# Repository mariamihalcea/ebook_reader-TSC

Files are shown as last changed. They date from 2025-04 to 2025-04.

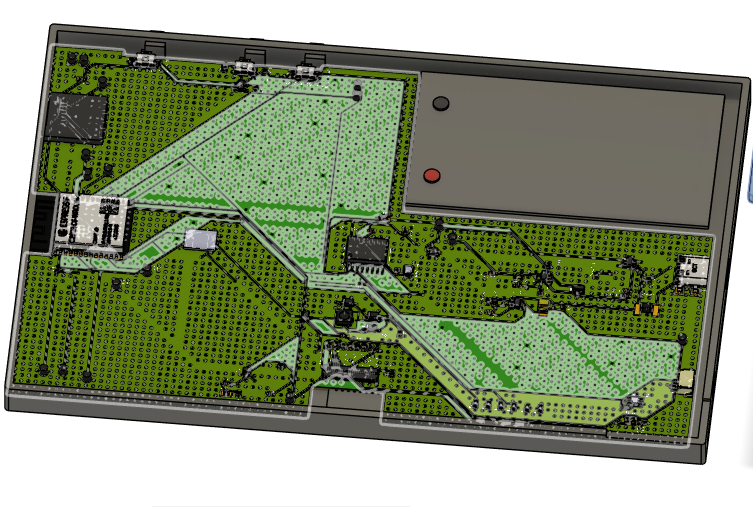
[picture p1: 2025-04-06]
Images/OpenBook_without_lid.png

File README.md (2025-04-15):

# OpenBook E-Reader 

## 1. Diagrama bloc


**Descriere:**

- Microcontrollerul **ESP32-C6** este unitatea centrala care gestioneaza comunicarea cu toate modulele periferice.
- Display-ul e-paper este controlat de un circuit dedicat de comanda.
- Senzorul ambiental **BME688** masoara calitatea aerului si temperatura.
- Memoria externa NOR Flash (64MB) si cardul SD permit stocarea fisierelor (eBook-uri, configurari etc).
- RTC-ul **DS3231SN** asigura ora exacta in mod autonom, chiar si in lipsa alimentarii.
- Incarcarea bateriei Li-Po se face prin USB-C, cu protectie ESD si monitorizare a nivelului de incarcare (MAX17048).
- Butoanele fizice permit resetul sistemului si selectii de tip boot.

---

## 2. Bill Of Materials (BOM)
| Componenta | Link | Datasheet |
|---|---|---|
| BUTTON | [Model](https://industry.panasonic.com/global/en/products/control/switch/light-touch/number/evqpuj02k) | [Datasheet](https://www.lcsc.com/datasheet/lcsc_datasheet_2201121800_PANASONIC-EVQPUJ02K_C2936858.pdf) |
| CAPACITOR | [Model](https://componentsearchengine.com/part-view/R0402%201%25%20100%20K%20(RC0402FR-07100KL)/YAGEO) | [Datasheet](//efaidnbmnnnibpcajpcglclefindmkaj/https://www.resistor.com/assets/pdf/0402tstd.pdf) |
| CPH3225A | [Model](https://www.snapeda.com/parts/CPH3225A/Seiko+Instruments/view-part/?ref=eda) | [Datasheet](https://octopart.com/datasheet/cph3225a-seiko-25340571) |
| EVQPUJ02K | [Model](https://industry.panasonic.com/global/en/products/control/switch/light-touch/number/evqpuj02k) | [Datasheet](https://www.lcsc.com/datasheet/lcsc_datasheet_2201121800_PANASONIC-EVQPUJ02K_C2936858.pdf) |
| KP-1608SURCK | [Model](https://www.snapeda.com/parts/KP-1608SURCK/Kingbright/view-part/?ref=search&t=LED%200603) | [Datasheet](//efaidnbmnnnibpcajpcglclefindmkaj/https://media.elv.com/file/107153_led_surck1608_data.pdf) |
| USBLC6-2SC6Y | [Model](https://www.snapeda.com/parts/USBLC6-2SC6Y/STMicroelectronics/view-part/?ref=eda) | [Datasheet](https://www.digikey.com/en/htmldatasheets/production/1375342/0/0/1/usblc6-2sc6y) |
| SD0805S020S1R0 | [Model](https://ro.mouser.com/ProductDetail/KYOCERA-AVX/SD0805S020S1R0?qs=jCA%252BPfw4LHbpkAoSnwrdjw%3D%3D) | [Datasheet](https://www.alldatasheet.com/view.jsp?Searchword=SD0805S&sField=2) |
| PGB1010603MR | [Model](https://www.snapeda.com/parts/PGB1010603MR/Littelfuse/view-part/?ref=eda) | [Datasheet](https://www.alldatasheet.com/view.jsp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) |
| BD5229G-TR  | [Model](https://componentsearchengine.com/part-view/BD5229G-TR/ROHM%20Semiconductor) | [Datasheet](https://www.lcsc.com/datasheet/lcsc_datasheet_2201131330_ROHM-Semicon-BD5229G-TR_C962636.pdf) |
| XC6220A331MR-G | [Model](https://componentsearchengine.com/part-view/XC6220A331MR-G/Torex) | [Datasheet](https://www.alldatasheet.com/view.jsp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) |
| XC6220A331MR-G | [Model](https://componentsearchengine.com/part-view/XC6220A331MR-G/Torex) | [Datasheet](https://www.alldatasheet.com/view.jsp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) |
| USB4110-GF-A  | [Model](https://componentsearchengine.com/part-view/USB4110-GF-A/GCT%20(GLOBAL%20CONNECTOR%20TECHNOLOGY)) | [Datasheet](//efaidnbmnnnibpcajpcglclefindmkaj/https://gct.co/files/drawings/usb4110.pdf) |
| Adafruit | [Model](https://eu.mouser.com/ProductDetail/Adafruit/4208?qs=PzGy0jfpSMtbScLbr0L5dw%3D%3D) | [Datasheet](https://www.arrow.com/en/manufacturers/adafruit-industries/datasheets) |
| Bobina | [Model](https://store.comet.srl.ro/Catalogue/Product/43497/) | [Datasheet](https://www.scribd.com/document/814581278/Datasheet-Bobina) |
| PFMF | [Model](https://www.mouser.co.uk/ProductDetail/EPCOS-TDK/B72520T0350K062?qs=dEfas%2FXlABIszF52uu7vrg%3D%3D) | [Datasheet](https://ro.mouser.com/c/ds/circuit-protection/thermistors/resettable-fuses-pptc/?m=Schurter&series=PFMF) |
| DMG2305UX-7 | [Model](https://componentsearchengine.com/part-view/DMG2305UX-7/Diodes%20Incorporated) | [Datasheet](//efaidnbmnnnibpcajpcglclefindmkaj/https://www.mouser.com/datasheet/2/115/DMG2305UX-266242.pdf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) |
| Si1308EDL-T1-GE3 | [Model](https://componentsearchengine.com/part-view/SI1308EDL-T1-GE3/Vishay) | [Datasheet](https://www.alldatasheet.com/view.jsp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) |
| R0402 | [Model](https://componentsearchengine.com/part-view/R0402%201%25%20100%20K%20(RC0402FR-07100KL)/YAGEO) | [Datasheet](//efaidnbmnnnibpcajpcglclefindmkaj/https://www.resistor.com/assets/pdf/0402tstd.pdf) |
| BME680 | [Model](https://www.snapeda.com/parts/BME680/Bosch/view-part/?welcome=home) | [Datasheet](//efaidnbmnnnibpcajpcglclefindmkaj/https://www.bosch-sensortec.com/media/boschsensortec/downloads/datasheets/bst-bme680-ds001.pdf) |
| SMD Solder | [Model](https://grabcad.com/library/solder-jumpers-1) | [Datasheet]() |
| W25Q512JVEIQ | [Model](https://www.snapeda.com/parts/ESP32-C6-WROOM-1-N8/Espressif+Systems/view-part/?ref=eda) | [Datasheet](//efaidnbmnnnibpcajpcglclefindmkaj/https://www.mouser.com/datasheet/2/949/W25Q512JV_SPI_RevB_06252019_KMS-2487502.pdf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) |
| ESP32-C6-WROOM-1-N8 | [Model](https://www.snapeda.com/parts/ESP32-C6-WROOM-1-N8/Espressif+Systems/view-part/?ref=eda) | [Datasheet](//efaidnbmnnnibpcajpcglclefindmkaj/https://www.mouser.com/catalog/specsheets/Espressif_ESP32_C6_WROOM_1%20_Datasheet_V0.1_PRELIMINARY_en.pdf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) |
| DS3231SN# | [Model](https://www.snapeda.com/parts/DS3231SN%23/Analog+Devices/view-part/?ref=eda) | [Datasheet](https://www.alldatasheet.com/view.jsp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) |
| MAX17048G+T10 | [Model](https://www.snapeda.com/parts/MAX17048G+T10/Analog+Devices/view-part/?ref=eda) | [Datasheet](https://www.alldatasheet.com/view.jsp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) |
| MCP73831T-5ACI/OT | [Model](https://www.mouser.co.uk/ProductDetail/Microchip-Technology/MCP73831T-5ACI-OT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) | [Datasheet](//efaidnbmnnnibpcajpcglclefindmkaj/https://ww1.microchip.com/downloads/en/DeviceDoc/MCP73831-Family-Data-Sheet-DS20001984H.pdf) |

## 3. Descriere hardware detaliata

###  Microcontroller – ESP32-C6
- Controleaza toate componentele externe prin GPIO, I2C, SPI.

### E-paper Display + Driver
- Controlat prin SPI, cu tensiune separata de alimentare si control.

###  RTC – DS3231SN
- Ceas in timp real cu precizie mare si backup pe baterie.
- Comunicatie I2C cu ESP32-C6.
- Folosit pentru afisarea orei si sincronizare evenimente programate.

### Card SD
- Legat la ESP32 prin SPI.
- Utilizat pentru incarcare/citire fisiere eBook, configurari etc.

###  Senzor mediu – BME688
- Comunica prin I2C.
- Masoara temperatura, presiune, umiditate si compusi volatili.

###  Conector USB-C
- Folosit pentru incarcare si posibila conectare seriala cu PC pentru debug.

##  4. Conexiuni ESP32-C6

| Componenta | Pin ESP32-C6 | Interfata | Motiv utilizare |
|---|---|---|---|
| E-paper Display | IO06, IO07, IO08  | SPI | Transfer rapid de date catre display |
| Flash NOR | IO10, IO11, IO12  | SPI | Stocare externa rapida |
| Senzor BME688 | IO18 (SDA), IO19 (SCL) | I2C | Comunicare cu senzori |
| RTC DS3231SN | IO18, IO19 | I2C | Reutilizeaza magistrala I2C |
| MAX17048 (Baterie) | IO18, IO19 | I2C | Monitor baterie, I2C comun |
| SD Card | IO01, IO02, IO03  | SPI | Citire fisiere eBook |
| Buton reset/boot | IO00, EN | GPIO | Control boot si reset manual |

---

## 5. Pasi de implementare

### 1. Analiza documentatiei initiale
Am analizat schematicul si layout-ul placii furnizate de profesor. Pe baza acestora, am recreat designul electronic in Fusion Electronics, atat schema electrica, cat si placa PCB.

### 2. Plasarea componentelor pe PCB
Am asezat componentele pe placa, urmarind o pozitionare si orientare optime, pentru a permite o rutare eficienta si functionala.

### 3. Rutarea traseelor
Traseele de alimentare au fost rutate manual pentru a asigura robustete si dimensiuni corecte. Conexiunile ramase au fost rutate automat, folosind functia de autorouting pe ambele straturi (top si bottom). Am adaugat polygon pour pentru a crea plane de masa pe ambele straturi.

### 4. Optimizarea layout-ului
Am folosit vias pentru a conecta planele de masa intre straturi si pentru a completa zonele neconectate. Am aplicat via stitching pentru a imbunatati integritatea electrica a designului.

### 5. Generarea modelului 3D al placii
Pe baza designului 2D, am generat modelul 3D al placii. Am cautat si importat manual fiecare componenta 3D, pozitionandu-le conform plasamentului din PCB-ul 2D. Pentru componenta *test pad*, neavand un model disponibil online, am creat manual unul pentru a reprezenta corect placa in ansamblu.

### 6. Integrarea in ansamblul final – OpenBook Enclosure
Am importat modelul 3D al placii in fisierul principal al carcasei (OpenBook Enclosure). Acolo am plasat toate componentele in carcasa finala pentru a asigura o potrivire corecta si functionala. Display-ul si bateria au fost desenate manual pentru a fi integrate in ansamblu si pentru a oferi o reprezentare cat mai realista a produsului final.
##  6. Alte detalii relevante

La realizarea PCB-ului am intampinat si doua erori de Copper Width, desi aveam  dimensiunile corespunzatoare, asa ca le-am aprobat.

<br>
si doua erori din cauza dimensiunii gaurilor din mufa USB, pe care de asemenea le am aprobat


---

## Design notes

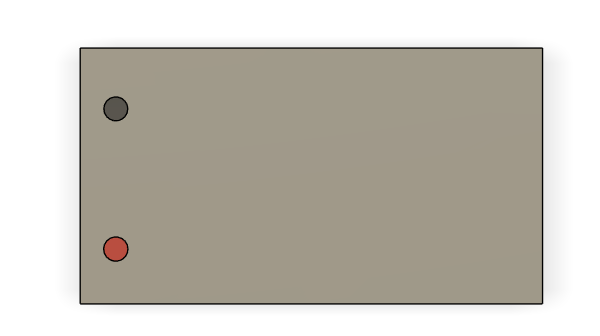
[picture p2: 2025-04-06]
Images/battery.png

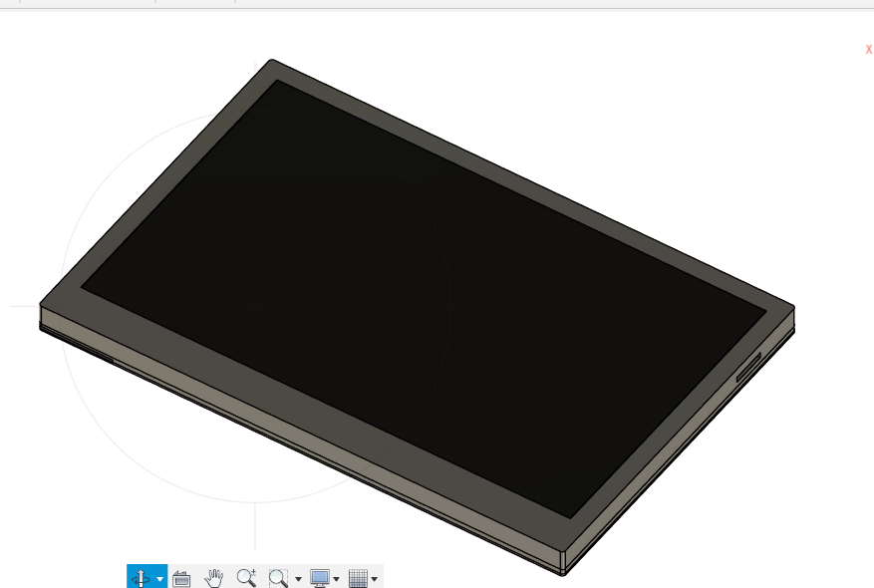
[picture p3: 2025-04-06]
Images/board_bottom.png

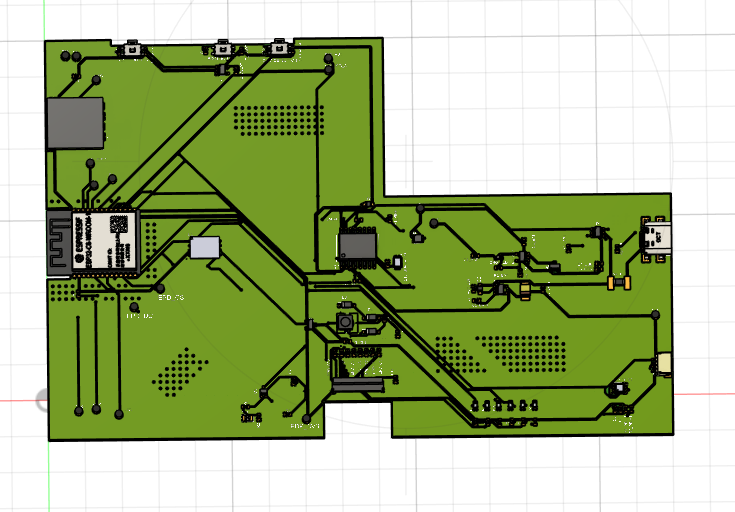
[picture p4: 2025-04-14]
Images/pcb-top.png

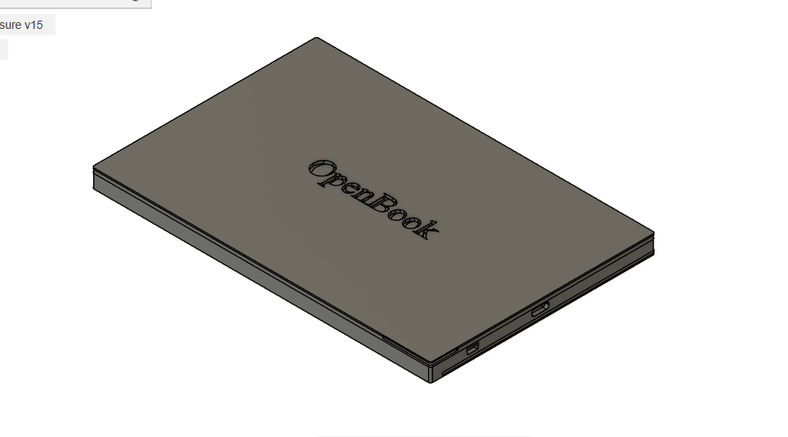
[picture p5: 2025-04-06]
Images/OpenBook.png

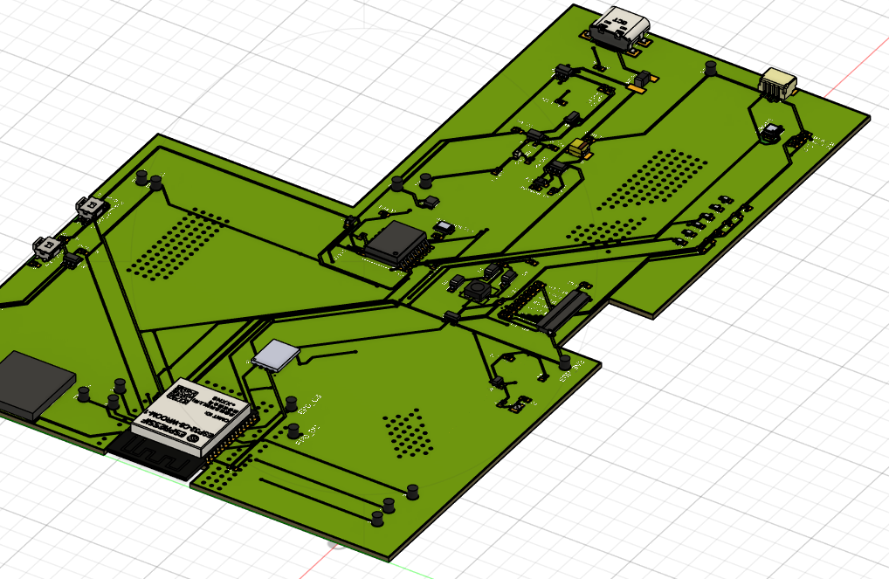
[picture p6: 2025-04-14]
Images/pcb.png

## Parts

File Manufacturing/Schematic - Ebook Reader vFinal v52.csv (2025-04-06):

Qty | Value | Device | Package | Parts | Description | ARROW_PART_NUMBER | ARROW_PRICE-STOCK | AVAILABILITY | CENTROID_NOT_SPECIFIED | CHECK_PRICES | COPYRIGHT | DATASHEET | DESCRIPTION | DIGIKEY_DESCRIPTION | DIGIKEY_PART_NUMBER | HEIGHT | LEAD_FREE | MANUFACTURER_NAME | MANUFACTURER_PART_NUMBER | MF | MFR_NAME | MOUSER_PART_NUMBER | MOUSER_PRICE-STOCK | MOUSER_TESTING_PART_NUMBER | MOUSER_TESTING_PRICE-STOCK | MP | MPN | PACKAGE | POPULARITY | PREFIX | PRICE | PROD_ID | PURCHASE-URL | ROHS | SNAPEDA_LINK | SPICEMODEL | SPICEPREFIX | TEMPERATURE_RANGE_HIGH | TEMPERATURE_RANGE_LOW | TP_SIGNAL_NAME | VALUE
1 |  | ADAFRUIT_LEDCHIP-LED0603 | ADAFRUIT_CHIP-LED0603 | CHG_LED | LED
1 |  | SJ | SJ | SJ1 | SMD solder JUMPER |  |  |  |  |  |  |  |  |  |  |  |  |  |  |  |  |  |  |  |  |  |  |  | 3
1 | 0.1uF_50V | EAGLE-LTSPICE_CC0402 | EAGLE-LTSPICE_C0402 | EPD_C5 | CAPACITOR, European symbol |  |  |  |  |  |  |  |  |  |  |  |  |  |  |  |  |  |  |  |  |  |  |  |  |  |  |  |  |  |  | NONE | C
1 | 0.47 | ESP32_WROVER_EAGLE-LTSPICE_RR0402 | ESP32_WROVER_EAGLE-LTSPICE_R0402 | R3 | RESISTOR, European symbol |  |  |  |  |  |  |  |  |  |  |  |  |  |  |  |  |  |  |  |  |  |  |  |  |  |  |  |  |  |  | NONE | R
1 | 100K | ESP32_WROVER_EAGLE-LTSPICE_RR0402 | ESP32_WROVER_EAGLE-LTSPICE_R0402 | R1_PWRUSB | RESISTOR, European symbol |  |  |  |  |  |  |  |  |  |  |  |  |  |  |  |  |  |  |  |  |  |  |  |  |  |  |  |  |  |  | NONE | R
8 | 100nF | EAGLE-LTSPICE_CC0402 | EAGLE-LTSPICE_C0402 | C1, C2, C4_USB, C6, C8, C9, C10, C_DELAY | CAPACITOR, European symbol |  |  |  |  |  |  |  |  |  |  |  |  |  |  |  |  |  |  |  |  |  |  |  |  |  |  |  |  |  |  | NONE | C
1 | 100uF TANT | RCL_CPOL-EUCT3528 | RCL_CT3528 | C3 | POLARIZED CAPACITOR, European symbol |  |  |  |  |  |  |  |  |  |  |  |  |  |  |  |  |  |  |  |  |  |  |  | 0 |  |  |  |  |  |  |  | C
13 | 10K | ESP32_WROVER_EAGLE-LTSPICE_RR0402 | ESP32_WROVER_EAGLE-LTSPICE_R0402 | R1, R1_PINH, R1_PINH1, R4, R5, R6, R7, R8, R9, R10, R_BOOT, R_CHANGE, R_RESET | RESISTOR, European symbol |  |  |  |  |  |  |  |  |  |  |  |  |  |  |  |  |  |  |  |  |  |  |  |  |  |  |  |  |  |  | NONE | R
3 | 10k | ESP32_WROVER_EAGLE-LTSPICE_RR0402 | ESP32_WROVER_EAGLE-LTSPICE_R0402 | R2_PINH, R2_PINH1, R_CL1 | RESISTOR, European symbol |  |  |  |  |  |  |  |  |  |  |  |  |  |  |  |  |  |  |  |  |  |  |  |  |  |  |  |  |  |  | NONE | R
1 | 10uF | EAGLE-LTSPICE_CC0402 | EAGLE-LTSPICE_C0402 | C7 | CAPACITOR, European symbol |  |  |  |  |  |  |  |  |  |  |  |  |  |  |  |  |  |  |  |  |  |  |  |  |  |  |  |  |  |  | NONE | C
1 | 112A-TAAR-R03_ATTEND | 112A-TAAR-R03_ATTEND | 112ATAARR03ATTEND | J4 | Micro SD Card Socket, Push-Push Type, Top Mount, SMT, H=1.83mm, 10u |  |  |  |  |  |  |  | Micro SD Card Socket | Push-Push Type | Top Mount | SMT | H=1.83mm | 10u |  |  | 1.9mm |  | ATTEND | 112A-TAAR-R03 ATTEND
1 | 15 | ESP32_WROVER_EAGLE-LTSPICE_RR0402 | ESP32_WROVER_EAGLE-LTSPICE_R0402 | R_CAPACITOR | RESISTOR, European symbol |  |  |  |  |  |  |  |  |  |  |  |  |  |  |  |  |  |  |  |  |  |  |  |  |  |  |  |  |  |  | NONE | R
1 | 1uF | EAGLE-LTSPICE_CC0402 | EAGLE-LTSPICE_C0402 | C5 | CAPACITOR, European symbol |  |  |  |  |  |  |  |  |  |  |  |  |  |  |  |  |  |  |  |  |  |  |  |  |  |  |  |  |  |  | NONE | C
1 | 1uF/50v | EAGLE-LTSPICE_CC0402 | EAGLE-LTSPICE_C0402 | EPD_C12 | CAPACITOR, European symbol |  |  |  |  |  |  |  |  |  |  |  |  |  |  |  |  |  |  |  |  |  |  |  |  |  |  |  |  |  |  | NONE | C
8 | 1uF_50V | EAGLE-LTSPICE_CC0402 | EAGLE-LTSPICE_C0402 | EPD_C1, EPD_C2, EPD_C6, EPD_C7, EPD_C8, EPD_C9, EPD_C10, EPD_C11 | CAPACITOR, European symbol |  |  |  |  |  |  |  |  |  |  |  |  |  |  |  |  |  |  |  |  |  |  |  |  |  |  |  |  |  |  | NONE | C
1 | 2.2 | ESP32_WROVER_EAGLE-LTSPICE_RR0402 | ESP32_WROVER_EAGLE-LTSPICE_R0402 | R2 | RESISTOR, European symbol |  |  |  |  |  |  |  |  |  |  |  |  |  |  |  |  |  |  |  |  |  |  |  |  |  |  |  |  |  |  | NONE | R
1 | 200 | ESP32_WROVER_EAGLE-LTSPICE_RR0402 | ESP32_WROVER_EAGLE-LTSPICE_R0402 | R1_BAT | RESISTOR, European symbol |  |  |  |  |  |  |  |  |  |  |  |  |  |  |  |  |  |  |  |  |  |  |  |  |  |  |  |  |  |  | NONE | R
2 | 20V/4.2A/52mO/1.4W | ESP32_WROVER_SPARKFUN-DISCRETESEMI_MOSFET_PCH-DMG2305UX-7 | ESP32_WROVER_SPARKFUN-DISCRETESEMI_SOT23-3 | Q1, Q2 | P-channel MOSFETs |  |  |  |  |  |  |  |  |  |  |  |  |  |  |  |  |  |  |  |  |  |  |  |  |  |  | TRAN-14388 |  |  |  |  |  |  |  |  | 20V/4.2A/52mO/1.4W
1 | 2K | ESP32_WROVER_EAGLE-LTSPICE_RR0402 | ESP32_WROVER_EAGLE-LTSPICE_R0402 | R2_BAT | RESISTOR, European symbol |  |  |  |  |  |  |  |  |  |  |  |  |  |  |  |  |  |  |  |  |  |  |  |  |  |  |  |  |  |  | NONE | R
5 | 4.7uF | EAGLE-LTSPICE_CC0402 | EAGLE-LTSPICE_C0402 | C1_BAT, C1_BAT1, C1_BAT2, C2_BAT, C5_USB | CAPACITOR, European symbol |  |  |  |  |  |  |  |  |  |  |  |  |  |  |  |  |  |  |  |  |  |  |  |  |  |  |  |  |  |  | NONE | C
1 | 4.7uF/25V | EAGLE-LTSPICE_CC0402 | EAGLE-LTSPICE_C0402 | C4 | CAPACITOR, European symbol |  |  |  |  |  |  |  |  |  |  |  |  |  |  |  |  |  |  |  |  |  |  |  |  |  |  |  |  |  |  | NONE | C
2 | 5k1 | ESP32_WROVER_EAGLE-LTSPICE_RR0402 | ESP32_WROVER_EAGLE-LTSPICE_R0402 | R2-USB, R2-USB1 | RESISTOR, European symbol |  |  |  |  |  |  |  |  |  |  |  |  |  |  |  |  |  |  |  |  |  |  |  |  |  |  |  |  |  |  | NONE | R
1 | 68uH | 744043680IND_4828-WE-TPC_WRE | IND_4828-WE-TPC_WRE | L1 |  |  |  |  |  |  | Copyright (C) 2024 Ultra Librarian. All rights reserved. |  |  |  |  |  |  |  | 744043680 |  | Wurth Electronics
1 | BD5229G-TR | BD5229G-TR | SOT95P280X125-5N | IC1 | Voltage Detector with Adjustable Delay Time: CMOS processes are utilized to develop high precision, low current consumption CMOS reset ICs that allow arbitrary setting of the delay time. The extensive lineup includes both Nch Open Drain and CMOS output types in a wide range of detection voltages (from 2.3V to 6.0V, in 0.1V steps), enabling selection of the ideal solution based on customer requirements. In addition, the entire series is of course both lead-free and RoHS-compliant. |  |  |  |  |  |  |  | Voltage Detector with Adjustable Delay Time: CMOS processes are utilized to develop high precision | low current consumption CMOS reset ICs that allow arbitrary setting of the delay time. The extensive lineup includes both Nch Open Drain and CMOS output types in a wide range of detection voltages (from 2.3V to 6.0V | in 0.1V steps) | enabling selection of the ideal solution based on customer requirements. In addition | the entire series is of course both lead-free and RoHS-compliant. |  |  | 1.25mm |  | ROHM Semiconductor | BD5229G-TR |  |  | 755-BD5229G-TR | https://www.mouser.co.uk/ProductDetail/ROHM-Semiconductor/BD5229G-TR?qs=4kLU8WoGk0vvnhrrYwdszw%3D%3D
1 | BME688 | ESP32_WROVER_BME680_BME680 | ESP32_WROVER_BME680_PSON80P300X300X100-8N | SENSOR2 | Integrated Environmental Unit |  |  | Unavailable |  |  |  |  | Integrated Environmental Unit |  |  |  |  |  |  | Bosch Sensortec |  |  |  |  |  | BME680 |  | LGA-8 Bosch Tools |  |  | None
3 | BUTTON_CUSYOMV1 | BUTTON_CUSYOMV1 | MYBUTTON | BOOT_BUTTON, CHANGE_BUTTON, RESET_BUTTON
1 | CPH3225A | CPH3225A | CAPCP3225X100N | C10_SUPERCAP | Cap 0.011F 3.3V 1210 Flat Check availability |  |  | Not in stock |  | https://www.snapeda.com/parts/CPH3225A/Seiko+Instruments/view-part/?ref=eda |  |  | 11 mF (EDLC) Supercapacitor 3.3 V 1210 (3225 Metric) - - |  |  |  |  |  |  | Seiko Instruments |  |  |  |  |  | CPH3225A |  | 1210 Seiko |  |  | None |  | https://www.snapeda.com/api/url_track_click_mouser/?unipart_id=562593&manufacturer=Seiko Instruments&part_name=CPH3225A&search_term=None |  | https://www.snapeda.com/parts/CPH3225A/Seiko+Instruments/view-part/?ref=snap
1 | DS3231SN# | DS3231SN# | SOIC127P1032X265-16N | U3 | Real Time Clock Serial 16-Pin SOIC W T/R Check availability |  |  | In Stock |  | https://www.snapeda.com/parts/DS3231SN%23/Analog+Devices/view-part/?ref=eda |  |  | Extremely Accurate I²C-Integrated RTC/TCXO/Crystal |  |  |  |  |  |  | Analog Devices |  |  |  |  |  | DS3231SN# |  | SOIC-16 Maxim |  |  | None |  | https://www.snapeda.com/api/url_track_click_mouser/?unipart_id=99048&manufacturer=Analog Devices&part_name=DS3231SN#&search_term=None |  | https://www.snapeda.com/parts/DS3231SN%23/Analog+Devices/view-part/?ref=snap
1 | ESP32-C6-WROOM-1-N8 | ESP32-C6-WROOM-1-N8 | XCVR_ESP32-C6-WROOM-1-N8 | U2 | Check availability |  |  | In Stock |  | https://www.snapeda.com/parts/ESP32-C6-WROOM-1-N8/Espressif+Systems/view-part/?ref=eda |  |  | Multiprotocol Modules ESP32-C6 module | Wi-Fi 6 in 2.4 GHz band | Bluetooth 5 | Zigbee 3.0 and Thread. ESP34-WROOM Compatible - ENGINEERING SAMPLE |  |  |  |  |  |  | Espressif Systems |  |  |  |  |  | ESP32-C6-WROOM-1-N8 |  | None |  |  | None |  |  |  | https://www.snapeda.com/parts/ESP32-C6-WROOM-1-N8/Espressif+Systems/view-part/?ref=snap
1 | ESP32C6_VARISTORCN1812 | ESP32C6_VARISTORCN1812 | ESP32C6_VARISTOR_CT/CN1812 | PFMF.050.1 | VARISTOR |  |  |  |  |  |  |  |  |  |  |  |  |  |  |  |  |  |  |  |  |  |  |  | 0
2 | ESP32_WROVER_AVX---SD0805S020S1R0_AVX_SD0805S020S1R0_0_0AVX_SD0805S020S1R0_0_0 | ESP32_WROVER_AVX---SD0805S020S1R0_AVX_SD0805S020S1R0_0_0AVX_SD0805S020S1R0_0_0 | ESP32_WROVER_AVX---SD0805S020S1R0_AVX_SD0805S020S1R0_0 | D2, D7 | Schottky Barrier Rectifier Diode |  |  |  | No |  |  | http://datasheets.avx.com/schottky.pdf |  | DIODE SCHOTTKY 20V 1A 0805 | 478-7800-1-ND |  | yes |  |  | AVX |  | 581-SD0805S020S1R0 |  |  |  |  |  | 0805 (2012 metric) |  | D |  |  |  | yes |  |  |  | +125°C | -55°C
1 | ESP32_WROVER_SPARKFUN-IC-POWER_MCP73831 | ESP32_WROVER_SPARKFUN-IC-POWER_MCP73831 | ESP32_WROVER_SPARKFUN-IC-POWER_SOT23-5 | MCP73831 | MCP73831T Li-Ion, Li-Pol Controller |  |  |  |  |  |  |  |  |  |  |  |  |  |  |  |  |  |  |  |  |  |  |  |  |  |  | IC-09995
1 | FH34SRJ-24S-0.5SH_99_ | FH34SRJ-24S-0.5SH_99_ | FH34SRJ24S05SH99 | J1 | (0.50mm) Surface Mount, Right Angle |  |  |  |  |  |  |  | 24 Position FFC | FPC Connector Contacts | (0.50mm) Surface Mount | Right Angle |  |  | 1.1mm |  | Hirose | FH34SRJ-24S-0.5SH(99) |  |  | 798-FH34SRJ24S05SH99 | https://www.mouser.co.uk/ProductDetail/Hirose-Connector/FH34SRJ-24S-0.5SH99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
1 | MAX17048G+T10 | MAX17048G+T10 | SON50P200X200X80-9N | U4 | Check availability |  |  | In Stock |  | https://www.snapeda.com/parts/MAX17048G+T10/Analog+Devices/view-part/?ref=eda |  |  | 3µA 1-Cell/2-Cell Fuel Gauge with ModelGauge |  |  |  |  |  |  | Analog Devices |  |  |  |  |  | MAX17048G+T10 |  | TDFN-8 Maxim |  |  | None |  | https://www.snapeda.com/api/url_track_click_mouser/?unipart_id=329239&manufacturer=Analog Devices&part_name=MAX17048G+T10&search_term=None |  | https://www.snapeda.com/parts/MAX17048G+T10/Analog+Devices/view-part/?ref=snap
3 | MBR0530 | MBR0530 | SOD3716X135N | D3, D4, D5 | ON SEMICONDUCTOR - MBR0530 - DIODE, SCHOTTKY, 0.5A, 30V, SOD-123 |  |  | In Stock |  | https://www.snapeda.com/parts/MBR0530/Onsemi/view-part/?ref=eda |  |  | Diode Schottky 30 V 500mA Surface Mount SOD-123 |  |  |  |  |  |  | ON Semiconductor |  |  |  |  |  | MBR0530 |  | SOD-123-2 ON Semiconductor |  |  | None |  | https://www.snapeda.com/api/url_track_click_mouser/?unipart_id=179458&manufacturer=ON Semiconductor&part_name=MBR0530&search_term=None |  | https://www.snapeda.com/parts/MBR0530/Onsemi/view-part/?ref=snap
6 | PGB1010603MR | PGB1010603MR | DIOC1608X36N | D6, D8, D9, D10, D11, D12 | Check availability |  |  | In Stock |  | https://www.snapeda.com/parts/PGB1010603MR/Littelfuse/view-part/?ref=eda |  |  | 150V (Typ) Clamp - Ipp Tvs Diode Surface Mount 0603 (1608 Metric) |  |  |  |  |  |  | Littelfuse Inc. |  |  |  |  |  | PGB1010603MR |  | 0603 Littelfuse Inc. |  |  | None |  | https://www.snapeda.com/api/url_track_click_mouser/?unipart_id=5659453&manufacturer=Littelfuse Inc.&part_name=PGB1010603MR&search_term=None |  | https://www.snapeda.com/parts/PGB1010603MR/Littelfuse/view-part/?ref=snap
1 | QWIIC_RIGHT_ANGLE | QWIIC_CONNECTORJS-1MM | JST04_1MM_RA | J3 | SparkFun I2C Standard Qwiic Connector |  |  |  |  |  |  |  |  |  |  |  |  |  |  |  |  |  |  |  |  |  |  |  |  |  |  | CONN-13694 |  |  |  |  |  |  |  |  | QWIIC_RIGHT_ANGLE
1 | SAMACSYS_PARTS_USB4110-GF-A | SAMACSYS_PARTS_USB4110-GF-A | SAMACSYS_PARTS_USB4110GFA | J2 | CONN USB 2.0 TYPE-C R/A SMT |  |  |  |  |  |  |  | CONN USB 2.0 TYPE-C R/A SMT |  |  | 3.26mm |  | GCT (GLOBAL CONNECTOR TECHNOLOGY) | USB4110-GF-A |  |  | 640-USB4110-GF-A | https://www.mouser.co.uk/ProductDetail/GCT/USB4110-GF-A?qs=KUoIvG%2F9IlYiZvIXQjyJeA%3D%3D
1 | SI1308EDL-T1-GE3 | SI1308EDL-T1-GE3 | SOT65P210X110-3N | Q3 | MOSFET N-Ch 30V 1.5A TrenchFET SC70 Vishay Si1308EDL-T1-GE3 N-channel MOSFET Transistor, 1.5 A, 30 V, 3-Pin SC-70 |  |  | In Stock |  | https://www.snapeda.com/parts/SI1308EDL-T1-GE3/Vishay+Siliconix/view-part/?ref=eda |  |  | Si1308EDL-T1-GE3 N-channel MOSFET Transistor | 1.5 A | 30 V | 3-Pin SC-70 | Siliconix / Vishay SI1308EDL-T1-GE3 |  |  |  |  |  |  | Vishay Siliconix |  |  |  |  |  | SI1308EDL-T1-GE3 |  | SOT-323 Vishay Semiconductor |  |  | None |  | https://www.snapeda.com/api/url_track_click_mouser/?unipart_id=274603&manufacturer=Vishay Siliconix&part_name=SI1308EDL-T1-GE3&search_term=None |  | https://www.snapeda.com/parts/SI1308EDL-T1-GE3/Vishay+Siliconix/view-part/?ref=snap
17 | TPTP20R | TPTP20R | TP20R | TP1, TP2, TP3, TP4, TP5, TP6, TP7, TP8, TP9, TP10, TP11, TP12, TP13, TP14, TP15, TP16, TP17 | Test pad |  |  |  |  |  |  |  |  |  |  |  |  |  |  |  |  |  |  |  |  |  |  |  | 2
1 | USBLC6-2SC6Y | USBLC6-2SC6Y | SOT95P280X145-6N | D1 | Low Cap. ESD Protection Auto SOT-23-6 STMicroelectronics USBLC6-2SC6Y, Dual Uni-Directional TVS Diode Array, 6-Pin SOT-23 |  |  | In Stock |  | https://www.snapeda.com/parts/USBLC6-2SC6Y/STMicroelectronics/view-part/?ref=eda |  |  | 17V Clamp 5A (8/20µs) Ipp Tvs Diode Surface Mount SOT-23-6 |  |  |  |  |  |  | STMicroelectronics |  |  |  |  |  | USBLC6-2SC6Y |  | SOT-23-6 STMicroelectronics |  |  | None |  |  |  | https://www.snapeda.com/parts/USBLC6-2SC6Y/STMicroelectronics/view-part/?ref=snap
1 | W25Q512JVEIQ | W25Q512JVEIQ | SON127P600X800X80-9N | U1 | Check availability |  |  | In Stock |  | https://www.snapeda.com/parts/W25Q512JVEIQ/Winbond+Electronics/view-part/?ref=eda |  |  | FLASH - NOR Memory IC 512Mb (64M x 8) SPI - Quad I/O 133 MHz 8-WSON (8x6) |  |  |  |  |  |  | Winbond Electronics |  |  |  |  |  | W25Q512JVEIQ |  | Package |  |  | None |  |  |  | https://www.snapeda.com/parts/W25Q512JVEIQ/Winbond+Electronics/view-part/?ref=snap
1 | XC6220A331MR-G | XC6220A331MR-G | SOT95P280X120-5N | IC4 | LDO Voltage Regulators |  |  |  |  |  |  |  | LDO Voltage Regulators |  |  | 1.2mm |  | Torex | XC6220A331MR-G |  |  | 865-XC6220A331MR-G | https://www.mouser.co.uk/ProductDetail/Torex-Semiconductor/XC6220A331MR-G?qs=AsjdqWjXhJ8ZSWznL1J0gg%3D%3D

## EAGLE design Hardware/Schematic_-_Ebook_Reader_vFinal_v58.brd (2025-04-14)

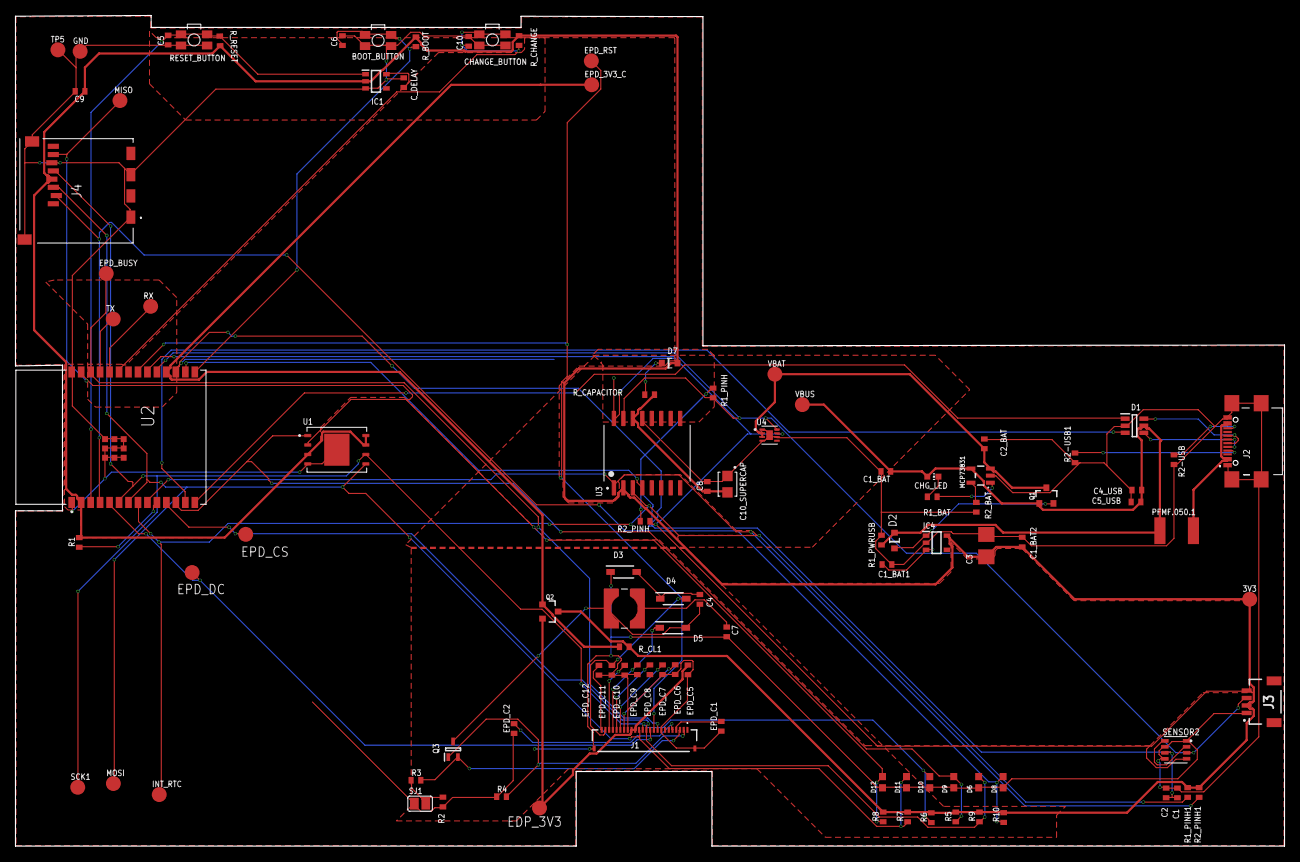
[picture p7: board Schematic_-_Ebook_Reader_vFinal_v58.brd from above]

Board: 2 copper layers, 170.2 x 111.4 mm, 103 parts (0 on the bottom side), 57 nets.

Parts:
3V3: TPTP20R; TP20R
BOOT_BUTTON: BUTTON_CUSYOMV1; MYBUTTON
C1, C2, C4_USB, C6, C8, C9, C10: 100nF; EAGLE-LTSPICE_C0402
C1_BAT, C1_BAT1, C1_BAT2, C2_BAT, C5_USB: 4.7uF; EAGLE-LTSPICE_C0402
C3: 100uF TANT; RCL_CT3528
C4: 4.7uF/25V; EAGLE-LTSPICE_C0402
C5: 1uF; EAGLE-LTSPICE_C0402
C7: 10uF; EAGLE-LTSPICE_C0402
C10_SUPERCAP: CPH3225A; CAPCP3225X100N
CHANGE_BUTTON: BUTTON_CUSYOMV1; MYBUTTON
CHG_LED: ADAFRUIT_CHIP-LED0603
C_DELAY: 100nF; EAGLE-LTSPICE_C0402
D1: USBLC6-2SC6Y; SOT95P280X145-6N
D2, D7: ESP32_WROVER_AVX---SD0805S020S1R0_AVX_SD0805S020S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; ESP32_WROVER_AVX---SD0805S020S1R0_AVX_SD0805S020S1R0_0
D3, D4, D5: MBR0530; SOD3716X135N
D6, D8, D9, D10, D11, D12: PGB1010603MR; DIOC1608X36N
EDP_3V3: TPTP20R; TP20R
EPD_3V3_C: TPTP20R; TP20R
EPD_BUSY: TPTP20R; TP20R
EPD_C1, EPD_C2, EPD_C6, EPD_C7, EPD_C8, EPD_C9, EPD_C10, EPD_C11: 1uF_50V; EAGLE-LTSPICE_C0402
EPD_C5: 0.1uF_50V; EAGLE-LTSPICE_C0402
EPD_C12: 1uF/50v; EAGLE-LTSPICE_C0402
EPD_CS: TPTP20R; TP20R
EPD_DC: TPTP20R; TP20R
EPD_RST: TPTP20R; TP20R
GND: TPTP20R; TP20R
IC1: BD5229G-TR; SOT95P280X125-5N
IC4: XC6220A331MR-G; SOT95P280X120-5N
INT_RTC: TPTP20R; TP20R
J1: FH34SRJ-24S-0.5SH_99_; FH34SRJ24S05SH99
J2: SAMACSYS_PARTS_USB4110-GF-A; SAMACSYS_PARTS_USB4110GFA
J3: QWIIC_RIGHT_ANGLE; JST04_1MM_RA
J4: 112A-TAAR-R03_ATTEND; 112ATAARR03ATTEND
L1: 68uH; IND_4828-WE-TPC_WRE
MCP73831: ESP32_WROVER_SPARKFUN-IC-POWER_MCP73831; ESP32_WROVER_SPARKFUN-IC-POWER_SOT23-5
MISO: TPTP20R; TP20R
MOSI: TPTP20R; TP20R
PFMF.050.1: ESP32C6_VARISTORCN1812; ESP32C6_VARISTOR_CT/CN1812
Q1, Q2: 20V/4.2A/52mΩ/1.4W; ESP32_WROVER_SPARKFUN-DISCRETESEMI_SOT23-3
Q3: SI1308EDL-T1-GE3; SOT65P210X110-3N
R1, R1_PINH, R1_PINH1, R4, R5, R6, R7, R8, R9, R10: 10K; ESP32_WROVER_EAGLE-LTSPICE_R0402
R1_BAT: 200; ESP32_WROVER_EAGLE-LTSPICE_R0402
R1_PWRUSB: 100K; ESP32_WROVER_EAGLE-LTSPICE_R0402
R2: 2.2; ESP32_WROVER_EAGLE-LTSPICE_R0402
R2-USB, R2-USB1: 5k1; ESP32_WROVER_EAGLE-LTSPICE_R0402
R2_BAT: 2K; ESP32_WROVER_EAGLE-LTSPICE_R0402
R2_PINH, R2_PINH1: 10k; ESP32_WROVER_EAGLE-LTSPICE_R0402
R3: 0.47; ESP32_WROVER_EAGLE-LTSPICE_R0402
RESET_BUTTON: BUTTON_CUSYOMV1; MYBUTTON
RX: TPTP20R; TP20R
R_BOOT: 10K; ESP32_WROVER_EAGLE-LTSPICE_R0402
R_CAPACITOR: 15; ESP32_WROVER_EAGLE-LTSPICE_R0402
R_CHANGE: 10K; ESP32_WROVER_EAGLE-LTSPICE_R0402
R_CL1: 10k; ESP32_WROVER_EAGLE-LTSPICE_R0402
R_RESET: 10K; ESP32_WROVER_EAGLE-LTSPICE_R0402
SCK1: TPTP20R; TP20R
SENSOR2: BME688; ESP32_WROVER_BME680_PSON80P300X300X100-8N
SJ1: SJ
TP5: TPTP20R; TP20R
TX: TPTP20R; TP20R
U1: W25Q512JVEIQ; SON127P600X800X80-9N
U2: ESP32-C6-WROOM-1-N8; XCVR_ESP32-C6-WROOM-1-N8
U3: DS3231SN#; SOIC127P1032X265-16N
U4: MAX17048G+T10; SON50P200X200X80-9N
VBAT: TPTP20R; TP20R
VBUS: TPTP20R; TP20R

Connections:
3V3: 3V3.TP, C1_BAT2.1, C3.+, C9.1, D7.2, IC1.2, IC4.5, J3.2, J4.P4, Q2.3, R1.2, R1_PINH1.2, R2_PINH1.2, R5.2, R6.2, R7.2, R8.2, R9.2, R10.2, R_BOOT.2, R_CHANGE.2, R_CL1.2, R_RESET.2, U1.3, U1.7, U1.8, U2.2, U3.2
32KHZ: R2_PINH1.1, U2.9, U3.1
DN: D1.4, J2.A7, J2.B7
DP: D1.6, J2.A6, J2.B6
EPD_3V3: EDP_3V3.TP, EPD_C5.2, J1.15, J1.16, Q2.2
EPD_3V3_C: EPD_3V3_C.TP, Q2.1, R_CL1.1, U2.18
EPD_BUSY: EPD_BUSY.TP, J1.9, U2.26
EPD_CS: D6.2, EPD_CS.TP, J1.12, R9.1, U2.11
EPD_DC: EPD_DC.TP, J1.11, U2.5
EPD_RST: EPD_RST.TP, J1.10, U2.21
FLASH_CS: D9.2, R5.1, U1.1, U2.12
GDR: J1.2, Q3.1, R4.2
GND: BOOT_BUTTON.1, BOOT_BUTTON.2, C1.2, C1_BAT.2, C1_BAT1.2, C1_BAT2.2, C2.2, C2_BAT.2, C3.-, C4_USB.2, C5.2, C5_USB.2, C6.2, C7.2, C8.2, C9.2, C10.2, C10_SUPERCAP.1, CHANGE_BUTTON.1, CHANGE_BUTTON.2, C_DELAY.2, D1.2, D3.1, D6.1, D8.1, D9.1, D10.1, D11.1, D12.1, EPD_C1.1, EPD_C2.1, EPD_C5.1, EPD_C6.1, EPD_C7.1, EPD_C9.1, EPD_C10.1, EPD_C11.1, EPD_C12.1, GND.TP, IC1.3, IC4.2, J1.8, J1.17, J1.MP1, J1.MP2, J2.A1, J2.A12, J2.B1, J2.B12, J2.MP1, J2.MP2, J2.MP3, J2.MP4, J3.1, J4.G1, J4.G2, J4.G3, J4.G4, J4.P6, MCP73831.2, R1_PWRUSB.2, R2.1, R2-USB.2, R2-USB1.1, R2_BAT.1, R4.1, RESET_BUTTON.1, RESET_BUTTON.2, SENSOR2.1, SENSOR2.5, SENSOR2.7, SJ1.1, TP5.TP, U1.4, U1.9, U2.1, U2.28, U2.29_1, U2.29_2, U2.29_3, U2.29_4, U2.29_5, U2.29_6, U2.29_7, U2.29_8, U2.29_9, U3.13, U4.1, U4.4, U4.6, U4.9
GPIO8: R1.1, U2.10
I2C_PW: C1.1, C2.1, R1_PINH.2, R2_PINH.2, SENSOR2.6, U2.17
INT_RTC: INT_RTC.TP, R1_PINH1.1, U2.8, U3.3
IO/BOOT: BOOT_BUTTON.3, BOOT_BUTTON.4, C6.1, R_BOOT.1, U2.15
IO/CHANGE: C10.1, CHANGE_BUTTON.3, CHANGE_BUTTON.4, R_CHANGE.1, U2.23
MISO: D12.2, J4.P7, MISO.TP, R8.1, U1.2, U2.27
MOSI: D11.2, J1.14, J4.P3, MOSI.TP, R7.1, U1.5, U2.7
unnamed: C1_BAT1.1, D2.1, IC4.1, IC4.3, Q1.2
unnamed: EPD_C2.2, J1.5
unnamed: J2.A5, R2-USB1.2
unnamed: C7.1, L1.2
unnamed: MCP73831.1, R1_BAT.2
unnamed: CHG_LED.C, R1_BAT.1
unnamed: C4.1, D3.2, D4.1
unnamed: MCP73831.5, R2_BAT.2
unnamed: C_DELAY.1, IC1.5
unnamed: D7.1, R_CAPACITOR.1
unnamed: EPD_C1.2, J1.4
unnamed: SENSOR2.2, SENSOR2.8
unnamed: J2.B5, R2-USB.1
unnamed: EPD_C6.2, J1.18
unnamed: EPD_C7.2, J1.19
unnamed: EPD_C8.2, J1.20
unnamed: EPD_C10.2, J1.22
unnamed: EPD_C12.2, J1.24
PREVGH: D5.1, EPD_C9.2, J1.21
PREVGL: D4.2, EPD_C11.2, J1.23
RESE: J1.3, Q3.2, R3.2
RESE': R2.2, R3.1, SJ1.2
RESET: C5.1, IC1.1, RESET_BUTTON.3, RESET_BUTTON.4, R_RESET.1, U2.3
RTC_RST: U2.16, U3.4
RX: RX.TP, U2.24
SCK: D10.2, J1.13, J4.P5, R6.1, SCK1.TP, U1.6, U2.6
SCL: J3.4, R2_PINH.1, SENSOR2.4, U2.20, U3.16, U4.7
SDA: J3.3, R1_PINH.1, SENSOR2.3, U2.19, U3.15, U4.8
SRC: C4.2, D5.2, L1.1, Q3.3
SS_SD: D8.2, J4.P2, R10.1, U2.4
TX: TX.TP, U2.25
USB_D+: D1.1, U2.14
USB_D-: D1.3, U2.13
VBAT: C2_BAT.1, MCP73831.3, Q1.3, U4.2, U4.3, VBAT.TP
VBUS: C1_BAT.1, C4_USB.1, C5_USB.1, CHG_LED.A, D1.5, D2.2, MCP73831.4, PFMF.050.1.2, Q1.1, R1_PWRUSB.1, VBUS.TP
VRTC: C8.1, C10_SUPERCAP.2, R_CAPACITOR.2, U3.14
VUSB: J2.A4, J2.A9, J2.B4, J2.B9, PFMF.050.1.1

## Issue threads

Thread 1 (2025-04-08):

Erori dimensiuni ecran

anaailiesei, 2025-04-08:
Ecranul nu respecta specificatiile din datasheet:
 - [ ] grosimea totala depaseste 1.18 mm (sunt doua straturi de 0.7 mm si 1.18 mm, dar ele impreuna trebuie sa aiba 1.18 mm).
 - [ ] marginile stratului superior nu respecta distantele fata de marginea layer-ului de dedesubt

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

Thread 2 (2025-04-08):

Plasare componente in carcasa

anaailiesei, 2025-04-08:
Componentele din carcasa se suprapun
 - [ ] #4

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

 - [ ] display-ul cu PCB-ul
 - [x] butoanele si 112A-TAAR-R03_ATTEND nu sunt aliniate corect cu carcasa

Closed 2025-04-14.

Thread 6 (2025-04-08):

Probleme Silkscreen

anaailiesei, 2025-04-08:
Am identificat urmatoarele probleme in Silkscreen:
 - [ ] test pad-urile nu sunt marcate cu numele semnalelor pe care le poartă
 - [ ] U2 nu apare pe silkscreen

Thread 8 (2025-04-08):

Probleme dimensiune baterie

anaailiesei, 2025-04-08:
Lungimea bateriei este prea mare (75.85 mm) si nu respecta cerintele din datasheet.

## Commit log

2025-04-06 Create OpenBook Enclosure v15.f3z
2025-04-14 Hardware updated
    [Schematic - Ebook Reader vFinal v37.sch, Schematic_-_Ebook_Reader_vFinal_v58.brd]

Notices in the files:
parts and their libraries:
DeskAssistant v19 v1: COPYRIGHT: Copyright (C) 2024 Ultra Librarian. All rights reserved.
